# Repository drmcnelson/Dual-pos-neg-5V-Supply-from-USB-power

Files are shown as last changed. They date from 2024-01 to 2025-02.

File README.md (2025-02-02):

# Dual-pos-neg-5V-Supply-from-USB-power
Provides +/-5 power from USB power, KiCAD design files.

## Introduction
This repository provides KiCAD files for a filtered +/-5V supply that I use with some of the precision instrumentation circuits that I build and use in my lab.  These are often operated by microcontrollers such as Arduino and Teensy that typically provide only +5V (USB) or 3.3V power.
While a lot can be done in designing for single ended supplies, there are some important instrumention circuits that inherently require a dual supply.

In this design, the +5V supply is based on an LT1930 configured as a SEPIC converter to accomodate 
supply voltages that may be greater or lesser than the 5V output.
The -5V suppy is based on an LT1931, an inverting DC/DC converter.
The datasheets describe the supplies as providing 350mA and 300mA, respectfully.
In this design, the circuits are connected by jumpers to the input power connector.
Either supply can be turned off individually by removing the corresponding jumper which is located next to the 5V input.

LT193n_+-5V_Supply

<br>
## Obtaining board

The board can be ordered, assembled, at

<a href="https://www.pcbway.com/project/shareproject/Power_supply_5V_5V_for_the_SPI_Instrumentation_project_987508ee.html">PCB from PCBWay</a>

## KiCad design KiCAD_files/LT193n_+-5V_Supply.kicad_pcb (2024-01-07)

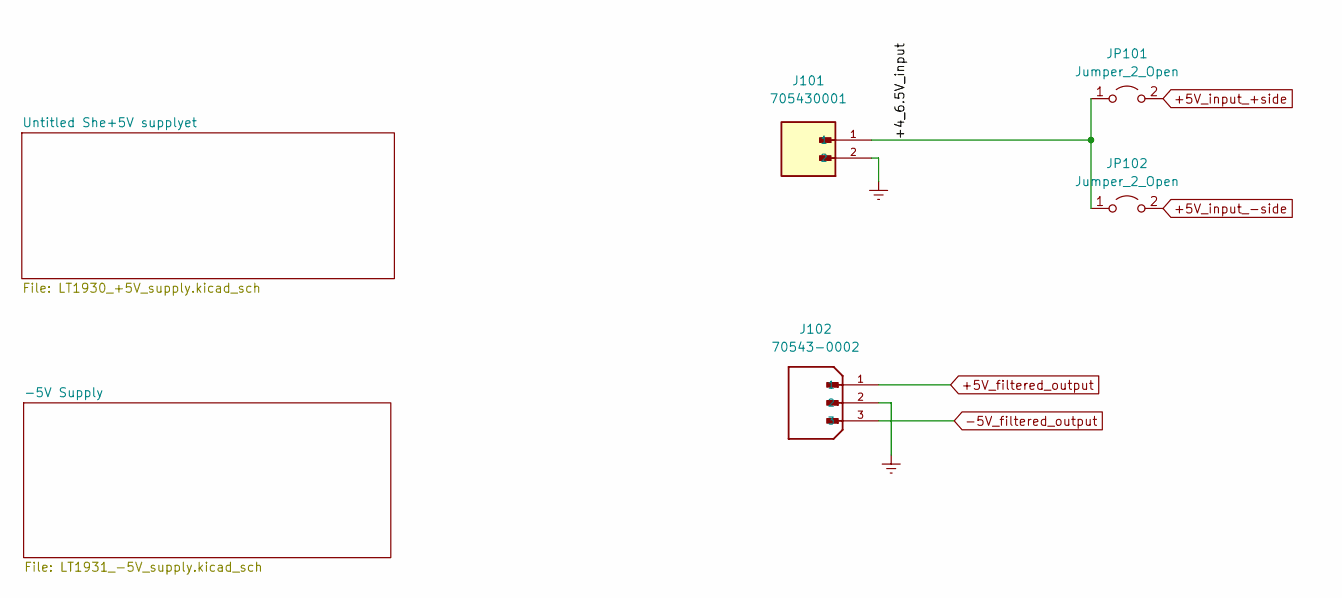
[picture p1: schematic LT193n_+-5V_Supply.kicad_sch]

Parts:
J101: 705430001; MOLEX_705430001; PARTREV M1; Digikey WM4800-ND
J102: 70543-0002; MOLEX_70543-0002; PARTREV M1; Digikey WM4801-ND
JP101, JP102: Jumper_2_Open; PinHeader_1x02_P2.54mm_Vertical; Digikey 3M156268-02-ND

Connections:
+5V_filtered_output: J102.1; also elsewhere on the board
+5V_input_+side: JP101.2 (B); also elsewhere on the board
+5V_input_-side: JP102.2 (B); also elsewhere on the board
-5V_filtered_output: J102.3; also elsewhere on the board
/+4_6.5V_input: J101.1, JP101.1 (A), JP102.1 (A)
Earth: J101.2, J102.2; also elsewhere on the board

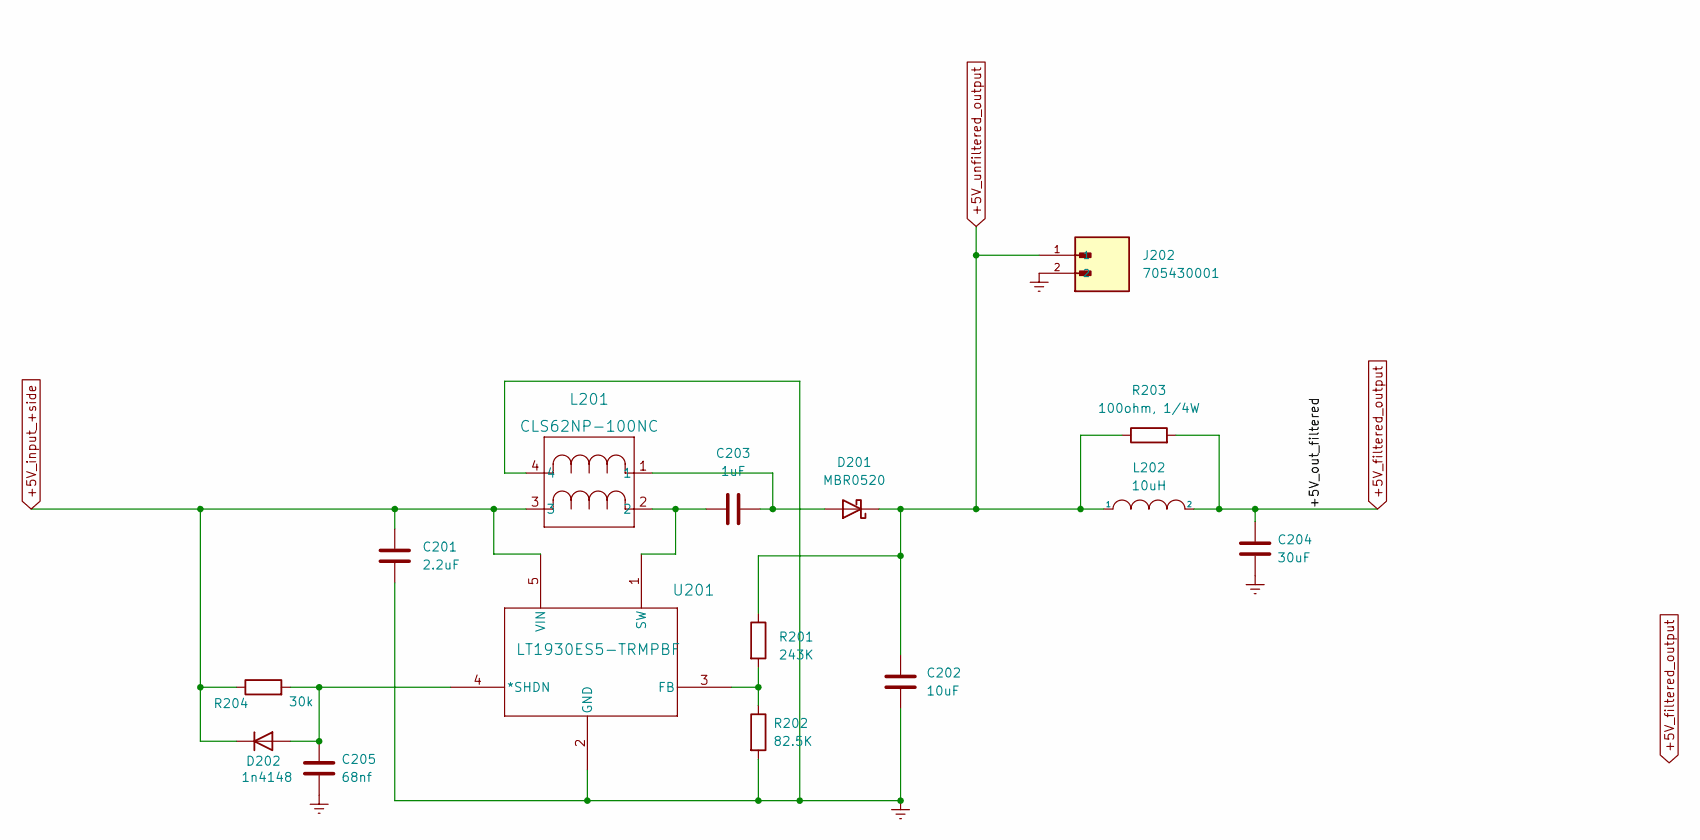
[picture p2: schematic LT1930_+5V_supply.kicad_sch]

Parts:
C201: 2.2uF; C_0805_2012Metric; Digikey 587-5919-1-ND
C202: 10uF; C_0805_2012Metric; Digikey 445-5984-1-ND
C203: 1uF; C_0805_2012Metric; Digikey 445-7547-1-ND
C204: 30uF; C_1206_3216Metric; Digikey 445-8046-1-ND
C205: 68nf; C_0805_2012Metric; Digikey 399-C0805C683K5RECAUTO7210CT-ND
D201: MBR0520; D_SOD-123; Digikey 3191-MBR0520CT-ND
D202: 1n4148; D_SOD-323; Digikey 1N4148WS-HE3-08GICT-ND
J202: 705430001; MOLEX_705430001; PARTREV M1; Digikey WM4800-ND
L201: CLS62NP-100NC; CLS62_SUM; Digikey 308-2327-1-ND
L202: 10uH; L_Taiyo-Yuden_NR-40xx; Digikey 587-2886-1-ND
R201: 243K; R_0805_2012Metric; Digikey RMCF0805FT243KCT-ND
R202: 82.5K; R_0805_2012Metric; Digikey RMCF0805FT82K5CT-ND
R203: 100ohm, 1/4W; R_0805_2012Metric; Digikey P16057CT-ND
R204: 30k; R_0805_2012Metric; Digikey 311-30.0KCRCT-ND
U201: LT1930ES5-TRMPBF; TSOT-23-5; Digikey 505-LT1930ES5#TRMPBFCT-ND

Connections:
+5V_filtered_output: C204.1, L202.2, R203.2; also elsewhere on the board
+5V_input_+side: C201.1, D202.1 (K), L201.3, R204.1, U201.5 (VIN); also elsewhere on the board
+5V_unfiltered_output: C202.1, D201.1 (K), J202.1, L202.1, R201.1, R203.1
Earth: C201.2, C202.2, C204.2, C205.2, J202.2, L201.4, R202.2, U201.2 (GND); also elsewhere on the board
unnamed: C203.1, L201.2, U201.1 (SW)
unnamed: C203.2, D201.2 (A), L201.1
unnamed: C205.1, D202.2 (A), R204.2, U201.4 (*SHDN)
unnamed: R201.2, R202.1, U201.3 (FB)

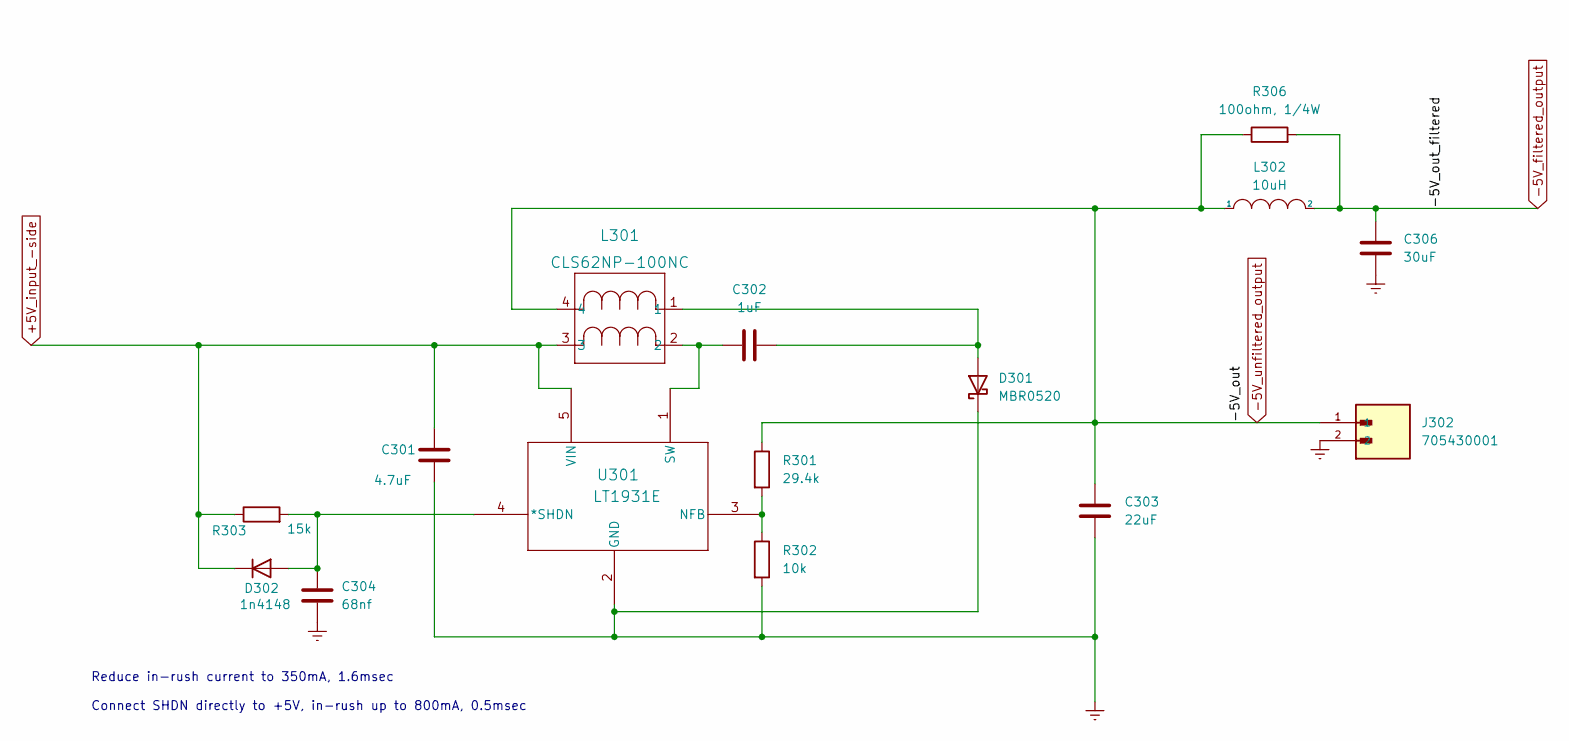
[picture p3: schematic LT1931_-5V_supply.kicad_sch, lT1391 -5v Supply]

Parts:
C301: 4.7uF; C_0805_2012Metric; Digikey 490-14532-1-ND
C302: 1uF; C_0805_2012Metric; Digikey 445-7547-1-ND
C303: 22uF; C_0805_2012Metric; Digikey 445-14428-1-ND
C304: 68nf; C_0805_2012Metric; Digikey 399-C0805C683K5RECAUTO7210CT-ND
C306: 30uF; C_1206_3216Metric; Digikey 445-8046-1-ND
D301: MBR0520; D_SOD-123; Digikey 3191-MBR0520CT-ND
D302: 1n4148; D_SOD-323; Digikey 1N4148WS-HE3-08GICT-ND
J302: 705430001; MOLEX_705430001; PARTREV M1; Digikey WM4800-ND
L301: CLS62NP-100NC; CLS62_SUM; Digikey 308-2327-1-ND
L302: 10uH; L_Taiyo-Yuden_NR-40xx; Digikey 587-2886-1-ND
R301: 29.4k; R_0805_2012Metric; Digikey 311-29.4KCRCT-ND
R302: 10k; R_0805_2012Metric; Digikey 311-10.0KCRCT-ND
R303: 15k; R_0805_2012Metric; Digikey 311-15.0KCRCT-ND
R306: 100ohm, 1/4W; R_0805_2012Metric; Digikey P16057CT-ND
U301: LT1931E; TSOT-23-5; Digikey 505-LT1931ES5#TRPBFCT-ND

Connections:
+5V_input_-side: C301.1, D302.1 (K), L301.3, R303.1, U301.5 (VIN); also elsewhere on the board
-5V_filtered_output: C306.1, L302.2, R306.2; also elsewhere on the board
-5V_unfiltered_output: C303.1, J302.1, L301.4, L302.1, R301.1, R306.1
Earth: C301.2, C303.2, C304.2, C306.2, D301.1 (K), J302.2, R302.2, U301.2 (GND); also elsewhere on the board
unnamed: C302.1, L301.2, U301.1 (SW)
unnamed: C302.2, D301.2 (A), L301.1
unnamed: C304.1, D302.2 (A), R303.2, U301.4 (*SHDN)
unnamed: R301.2, R302.1, U301.3 (NFB)

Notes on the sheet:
Reduce in-rush current to 350mA, 1.6msec Connect SHDN directly to +5V, in-rush up to 800mA, 0.5msec

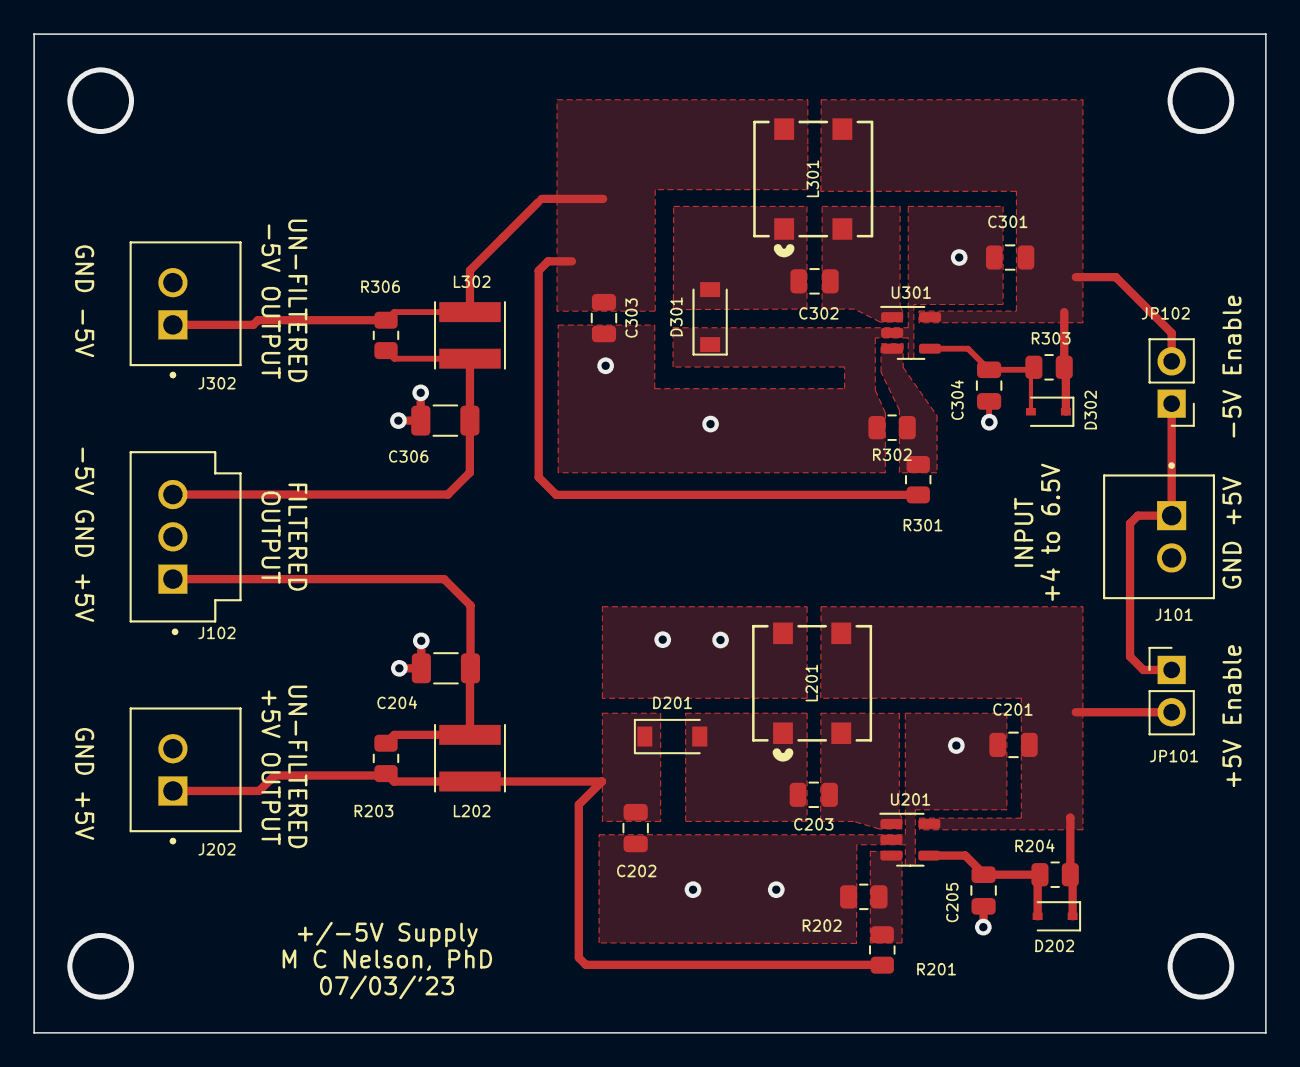
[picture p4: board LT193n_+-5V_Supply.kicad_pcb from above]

Board: 2 copper layers, 74.0 x 60.0 mm, 34 parts (0 on the bottom side), 16 nets.
